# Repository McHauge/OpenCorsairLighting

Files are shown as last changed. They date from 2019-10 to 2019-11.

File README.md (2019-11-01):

# OpenCorsairLighting
FOSSA Status (https://app.fossa.io/projects/git%2Bgithub.com%2FMcHauge%2FOpenCorsairLighting?ref=badge_shield)

In this repository you will find files and links associated with the creation of custom PCB's for opensource versions of the "Lighting Node Pro" and "Commander Pro" device, using motherboard USB and a Molex/SATA power. That allows for use with iCue from Corsair. The whole setup is based around the use of an ATMEGA32u4 with dedicated USB 2.0 build in, this processor is Arduino compatible and can be seen used in the "Arduino Leonardo" and "Spark Pro Micro".

# Software
**Module and examples made by Legion2 is available here:** https://github.com/Legion2/CorsairLightingProtocol

For the software, I recommend using the above-mentioned liberty and following the instructions available there.
When adding the boards "Lighting Node PRO" and "Commander Pro", then you can make use of the file "Boards.local.txt" under software and place it in the folder: "..\AppData\Local\arduino15\packages\arduino\hardware\avr\1.8.1" alongside the "Boards.txt".
Restart Arduino and now you should have two new boards available. 
These boards are bassed on the "Arduino Leonardo", and not the "Spark Pro Micro" as used by Legion2.

# Hardware
**PCB layout and design can be found in the hardware folder or at this link:** https://easyeda.com/OpenCorsairLighting

Both PCB's and components can be ordered directly from the link. 
After producing 10pcs of the V1.0 they ended up around 8-10$ per unit

## Related projects
- [CorsairLightingProtocol](https://github.com/Legion2/CorsairLightingProtocol)
- [CorsairArduinoController](https://github.com/TylerSeiford/CorsairArduinoController)

## License
FOSSA Status (https://app.fossa.io/projects/git%2Bgithub.com%2FMcHauge%2FOpenCorsairLighting?ref=badge_small)

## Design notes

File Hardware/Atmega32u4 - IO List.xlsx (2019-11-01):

Open Corsair Lighting Node Pro / Comander Pro
Pinout Diffenition from MCU To Board
Atmega32u4 - Based on Arduino Leonardo |  |  |  | Prefered Use:
Pin NR: | Pin Name: | Programing | Pin Diffenition: | Function: | Diffenition:
1 | PE6/INT6/AIN0/7 | D7 |  |  |  | Fan PWM 1-6
2 | UVCC | +5V |  | +5v USB |  | Power
3 | D- | RD- |  | USB D- |  | Temp 1-2
4 | D+ | RD+ |  | USB D+
5 | UGND | UGND |  | UGND |  | LED CH1-2
6 | UCAP | UCAP |  | UCAP |  | Krystal
7 | VBUS | VBUS |  | VBUS
8 | PB0/PCINT0/SS | RXLED |  | RXLED |  | USB
9 | PB1/PCINT1/SCLK | SCK | SPI |  |  | Program via USB
10 | PB2/PCINT2/PDI/MOSI | MOSI | SPI |  |  | Rx Tx led
11 | PB3/PCINT3/PDO/MISO | MISO | SPI
12 | PB7/PCINT7/OC0A/OC1C/RTS/11 | D11 | SPI CS | Fan 1
13 | RESET | RESET |  | RESET
14 | VCC | +5V |  | +5V
15 | GND | GND |  | GND
16 | XTAL2 | XTAL2 |  | Krystal
17 | XTAL1 | XTAL1 |  | Krystal
18 | PD0/INT0/OC0B/SCL/3 | D3 | SCL | PWM - Free
19 | PD1/INT1/SDA/2 | D2 | SDA
20 | PD2/INT2/RXD1/0 | D0 | UART RX
21 | PD3/INT3/TXD1/1 | D1 | UART TX
22 | PD5/XCK1/CTS | TXLED |  | TXLED
23 | GND | GND |  | GND
24 | AVCC | AVCC |  | +5V
25 | PD4/ICP1/ADC8/4 | D4 |  | LED CH1
26 | PD6/OC4D/T1/ADC9/12 | D12 |  | LED CH2
27 | PD7/OC4D/T0/ADC10/6 | D6 |  | Fan 2
28 | PB4/PCINT4/ADC11/8 | D8
29 | PB5/OC1A/OC4B/PCINT5/ADC12/9 | D9 |  | Fan 3
30 | PB6/OC1B/OC4B/PCINT6/ADC13/10 | D10 |  | Fan 4
31 | PC6/OC3A/OC4A/5 | D5 |  | Fan 5
32 | PC7/OC4A/CLK0/ICP3/13 | D13 |  | Fan 6
33 | PE2/HWB | HWB |  | USB Programming
34 | VCC | +5V |  | +5V
35 | GND | GND |  | GND
36 | PF7/TDI/ADC7/A0 | A0 |  | Temp 1
37 | PF6/TDO/ADC6/A1 | A1 |  | Temp 2
38 | PF5/TMS/ADC5/A2 | A2 |  | Temp 3
39 | PF4/TCK/ADC4/A3 | A3 |  | Temp 4
40 | PF1/ADC1/A4 | A4
41 | PF0/ADC0/A5 | A5
42 | AREF | AEF |  | +5V
43 | GND | GND |  | GND
44 | AVCC | AVCC |  | +5V

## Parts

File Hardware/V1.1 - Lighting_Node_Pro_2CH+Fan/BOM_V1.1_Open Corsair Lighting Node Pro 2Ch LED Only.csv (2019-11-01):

ID | Name | Designator | Footprint | Quantity | Manufacturer Part | Manufacturer | Supplier | Supplier Part | LCSC Assembly
1 | 22pF | C3,C4 | 0805' | 2 | CL21C220JBANNNC | SAMSUNG | LCSC | C1804 | Yes
2 | 210S-2*5P L=11.6MMGold-plated black | H2 | 210S-2.54-2X5P | 1 | 210S-2*5P L=11.6MMGold-plated black | Ckmtw | LCSC | C124387
3 | ATMEGA32U4-AU | U1 | QFP-44_10X10X08P | 1 | ATMEGA32U4-AU | MICROCHIP | LCSC | C44854 | Yes
4 | Header-Male-2.54_1x4 | H15,H14,H19,H18,H17,H16 | DIP-1X4P-2.54MM-M | 6 | 210S-1*4P L=11.6MMGold-plated black | Ckmtw | LCSC | C124378
5 | WJ2EDGVC-5.08-4P | P4 | WJ2EDGVC-5.08-4P | 1 | WJ2EDGVC-5.08-4P | ReliaPro | LCSC | C8436
6 | Header-Male-2.54_1x3 | P1,P2,P3 | HDR-3X1/2.54 | 3 | Header2.54mm 1*3P | BOOMELE | LCSC | C49257
7 | 1.02M | R3 | 0805' | 1 | 0805W8F1024T5E | UniOhm | LCSC | C57821 | Yes
8 | U254-051N-4BH83-S1B | USB1 | USB-MICRO-7.4X5.0-J | 1 | U254-051N-4BH83-S1B | XKB Enterprise | LCSC | C319168
9 | Header-Female-2.54_2x3 | H1 | HDR-3X2/2.54 | 1 | DS1023-2*3SF11 | CONNFLY | LCSC | C92272
10 | 22 | R2,R5,R1,R4 | 0805' | 4 | SR0805FR-0722RL | YAGEO | LCSC | C326853
11 | 10uF | C8 | 1206 | 1 | CL31A106KBHNNNE | SAMSUNG | LCSC | C13585 | Yes
12 | 1N4001F | D1 | SMAF_L3.5-W2.6-LS4.7-RD | 1 | 1N4001F | SK | LCSC | C122841 | Yes
13 | 1uF | C1,C7 | 0805' | 2 | TCC0805X7R105M160FT | CCTC | LCSC | C282738
14 | 100 | R8,R7,R6 | R1206 | 3 | AECR1206F100RK9 | ResistorToday | LCSC | C328408
15 | 1812L200/12DR | F1,F3,F2 | 1812 | 3 | 1812L200/12DR | Littelfuse | LCSC | C315901
16 | 100nF | C6,C5,C2,C9 | 1206 | 4 | CL31B104KBCNNNC | SAMSUNG | LCSC | C24497 | Yes
17 | 16MHz | X2 | HC-49S_L11.4-W4.8 | 1 | C16000J119 | ZheJiang East Crystal Elec | LCSC | C259047
18 | 1N4148W-TP | D4 | SOD-123_L2.8-W1.8-LS3.7-RD | 1 | 1N4148W-TP | MCC | LCSC | C77978 | Yes

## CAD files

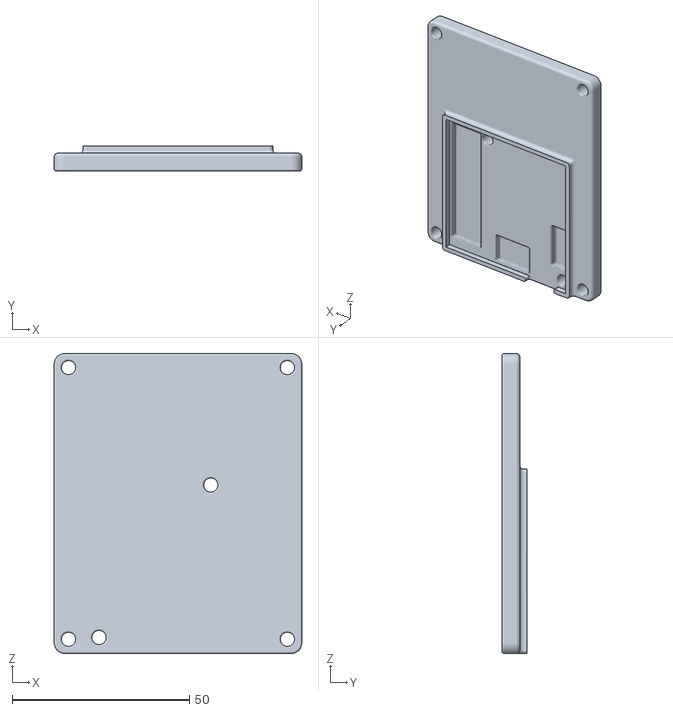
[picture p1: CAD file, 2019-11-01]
3D - Files/V1.1 - Mount - Lighting_Node_Pro_2CH+Fan/OpenCorsairMountSSD.stl
69.8 x 7.00 x 84.6

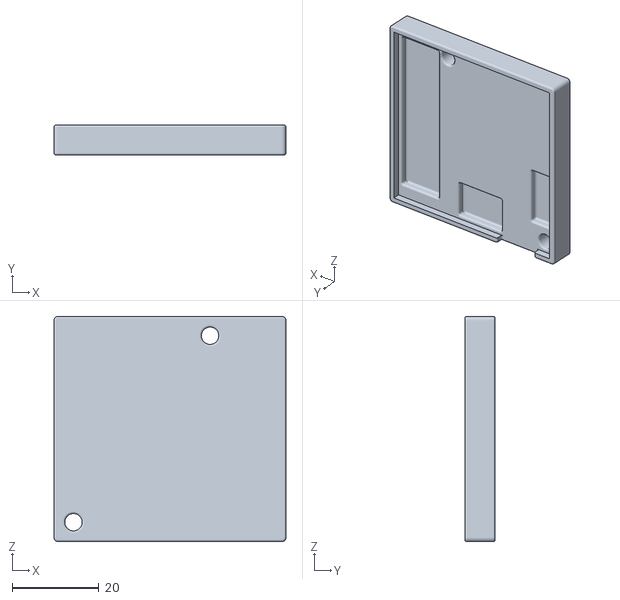
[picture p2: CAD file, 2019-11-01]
3D - Files/V1.1 - Mount - Lighting_Node_Pro_2CH+Fan/OpenCorsairMount.stl
53.5 x 7.00 x 52.0

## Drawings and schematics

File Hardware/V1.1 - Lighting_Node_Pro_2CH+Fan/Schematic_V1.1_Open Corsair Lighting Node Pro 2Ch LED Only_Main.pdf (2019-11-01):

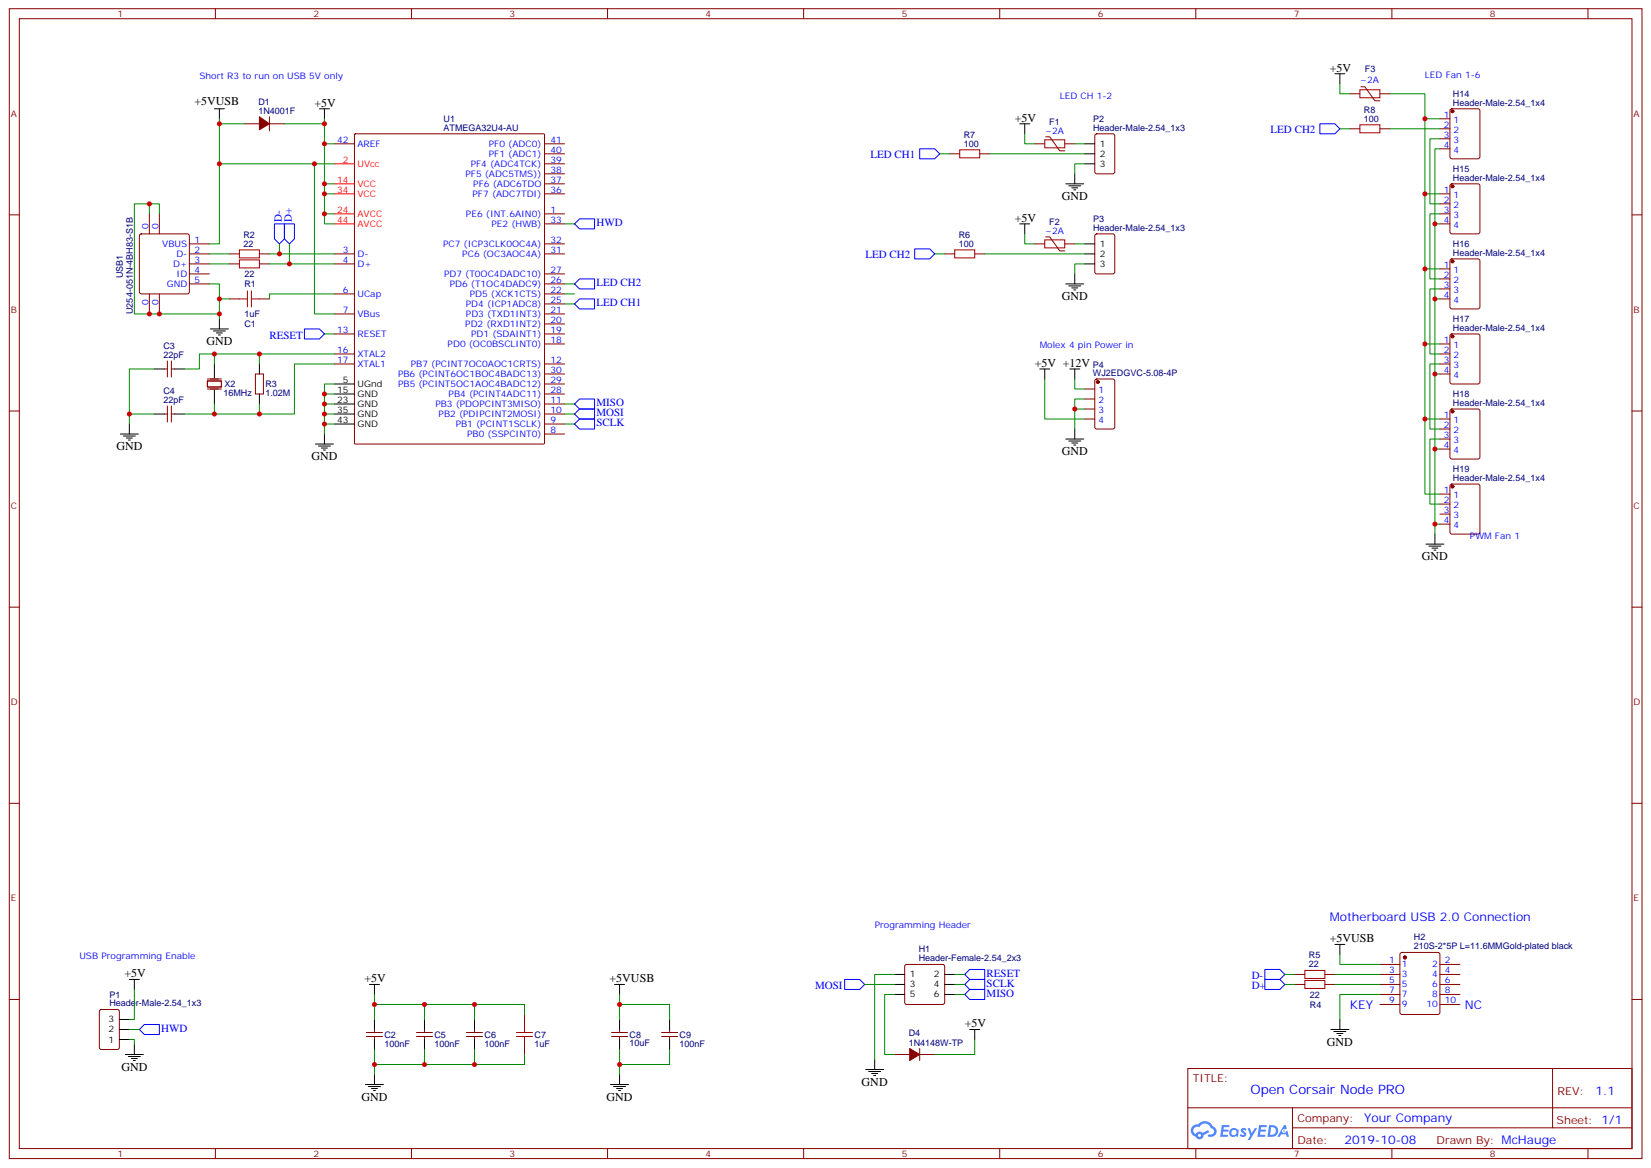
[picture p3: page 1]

Short R3 to run on USB 5V only

Molex 4 pin Power in

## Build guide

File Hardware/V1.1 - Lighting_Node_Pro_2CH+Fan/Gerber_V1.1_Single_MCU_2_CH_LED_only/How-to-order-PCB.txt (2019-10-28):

How to Order PCB

Please refer to:
https://docs.easyeda.com/en/PCB/Order-PCB

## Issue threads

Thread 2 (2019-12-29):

Programming

theorgBigBoss, 2019-12-29:
Hi
What is "USB Programming Enable" and "Programming Header" in the board?
is it possible to upload the code with normal USB? or i should upload the code using this headers?

McHauge, 2019-12-30:
Hi, the "USB Programming Enable" header is for use with other Atmel programmers, if you need to recover a bricked device.

When using Arduino you will need to use the "Programming header" also called an "ISP port" for burning the bootloader (this can be done with another Arduino or as I did with a TinyUSB programmer from Adafrouit), after that, you can use USB to program the device like any other Arduino, if something fails, then just re-install the bootloader again.

theorgBigBoss, 2019-12-30:
thanks for your answer
i want upload Legion2 code once and then just use for i,Cue
so if i burn bootloader with programmer ,can i remove "USB Programming Enable" and "Programming Header" safely?

McHauge, 2019-12-30:
yes, burn the bootloader and flash the firmware. the "USB Programming Enable" pin header is not required, I just added it if someone needed it, it can be ignored for normal use

Closed 2020-08-07.

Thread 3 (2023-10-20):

Polarity/placement of P4 (Molex) socket

barban-dev, 2023-10-20:
Hi,
based on the position of the +5V pin of the molex **CONNECTOR** (red wire)
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
it seems to me that the placement of P4 **SOCKET** is wrong:
AS-IS (wrong):
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
TO-BE (correction):
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

If it is right, P4 component  should be rotated 270 degree on the PickAndPlace file.

McHauge, 2023-10-30:
ehh, you might be right, It has been 4 years since I did them, and for me, I soldered them b and, so I might have messed that one up.

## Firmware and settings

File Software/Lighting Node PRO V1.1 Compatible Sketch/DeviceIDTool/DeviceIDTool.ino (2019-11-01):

/*
   Copyright 2019 Leon Kiefer

   Licensed under the Apache License, Version 2.0 (the "License");
   you may not use this file except in compliance with the License.
   You may obtain a copy of the License at

	 http://www.apache.org/licenses/LICENSE-2.0

   Unless required by applicable law or agreed to in writing, software
   distributed under the License is distributed on an "AS IS" BASIS,
   WITHOUT WARRANTIES OR CONDITIONS OF ANY KIND, either express or implied.
   See the License for the specific language governing permissions and
   limitations under the License.
*/
//
// UPLOAD THIS TO THE ARDUINO AND OPEN SERIAL MONITOR WITH BOUDRATE 115200
//
#include <EEPROM.h>
#include <CLPUtils.h>

#define EEPROM_ADDRESS_DEVICE_ID 0

bool isNullID(uint8_t* deviceId) {
	return !(deviceId[0] | deviceId[1] | deviceId[2] | deviceId[3]);
}

void setup() {
	Serial.begin(115200);
	Serial.setTimeout(100);
	uint8_t deviceID[4];
	EEPROM.get(EEPROM_ADDRESS_DEVICE_ID, deviceID);

	while (!Serial) {
		; // wait for serial port to connect. Needed for native USB
	}
	Serial.print(F("Current DeviceID: "));
	printDeviceID(deviceID);
	Serial.println();
	Serial.println(F("Set a new DeviceID by typing it in the Serial Monitor. The new DeviceID must be in same format as above. 4 Blocks with 2 digits separated by white space."));
	Serial.println();

}

void loop() {
	if (Serial.available()) {
		String inputString = Serial.readStringUntil('\n');
		if (inputString.length() < 11) {
			Serial.println(F("Input is too short!"));
			Serial.println(F("Do not forget the leading zeroes!"));
			Serial.println();
		}
		else {
			uint8_t newDeviceID[4];

			newDeviceID[0] = strtol(&inputString[0], NULL, 16);
			newDeviceID[1] = strtol(&inputString[3], NULL, 16);
			newDeviceID[2] = strtol(&inputString[6], NULL, 16);
			newDeviceID[3] = strtol(&inputString[9], NULL, 16);
			Serial.println(F("Set DeviceID to: "));
			printDeviceID(newDeviceID);
			Serial.println();
			if (isNullID(newDeviceID)) {
				Serial.println(F("This is a special DeviceID, it will generate a new random DeviceID next time iCUE controls the device!"));
			}
			Serial.println();
			EEPROM.put(EEPROM_ADDRESS_DEVICE_ID, newDeviceID);
		}
	}
}

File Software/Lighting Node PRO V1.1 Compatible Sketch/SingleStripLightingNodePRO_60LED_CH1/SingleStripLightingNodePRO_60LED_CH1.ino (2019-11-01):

/*
   Copyright 2019 Leon Kiefer

   Licensed under the Apache License, Version 2.0 (the "License");
   you may not use this file except in compliance with the License.
   You may obtain a copy of the License at

	   http://www.apache.org/licenses/LICENSE-2.0

   Unless required by applicable law or agreed to in writing, software
   distributed under the License is distributed on an "AS IS" BASIS,
   WITHOUT WARRANTIES OR CONDITIONS OF ANY KIND, either express or implied.
   See the License for the specific language governing permissions and
   limitations under the License.
*/
#include <CorsairLightingNodePRO.h>
#include <CorsairLightingProtocolHID.h>
#include <FastLED.h>

// The number of LEDs per channel, there are two channels.
// 60 LEDs per channel is the maximum iCUE can handle.
#define CHANNEL_LED_COUNT 60

// Total count of LEDs on all channels, the value is calculated based on the leds per channel.
#define NUM_LEDS (CHANNEL_LED_COUNT * 2)

// The Arduino pin where the physical LEDs are connected.
// You can use two pins, one for each channel.
// In this example we use only one pin where both channel are connected in series.
#define DATA_PIN 4

// Should the EEPROM of the Arduino be used to store persistent information like the Hardware Lighting.
// If enabled, the Hardware Lighting configured in iCUE works without a USB connection and even after a restart of the Arduino.
#define USE_EEPROM true

FastLEDController<CHANNEL_LED_COUNT> ledController(USE_EEPROM);
CorsairLightingProtocol cLP(&ledController, firmware_version);
CorsairLightingProtocolHID cHID(&cLP);

// This array conatins all RGB values for all LEDs of the both channels.
CRGB leds[NUM_LEDS];

void setup() {
#ifdef DEBUG
	Serial.begin(115200);
#endif
	disableBuildInLEDs();
	FastLED.addLeds<NEOPIXEL, DATA_PIN>(leds, NUM_LEDS);
	ledController.addLeds(0, leds);
	ledController.addLeds(1, &(leds[CHANNEL_LED_COUNT]));
}

void loop() {
	cHID.update();

	if (ledController.updateLEDs()) {
		FastLED.show();
	}
}

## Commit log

2019-10-28 Added V1.0 Hardware files
    [Atmega32u4 - IO List.xlsx, BOM_Open Corsair Lightning Node Pro 2Ch LED Only_20191008132037.csv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]
2019-11-01 Uploaded files for V1.1 and other smaller updates
    [Atmega32u4 - IO List.xlsx, BOM_Open Corsair Lightning Node Pro 2Ch LED Only_20191008132037.csv, BOM_V1.1_Open Corsair Lighting Node Pro 2Ch LED Only.csv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]
2019-11-01 Added Arduino Sketches compatible with Ligthing Node Pro V1.1
2019-11-01 Added 3D files for mounting as a SSD or with double sided tape
    [OpenCorsairMount.stl, OpenCorsairMountSSD.stl]
